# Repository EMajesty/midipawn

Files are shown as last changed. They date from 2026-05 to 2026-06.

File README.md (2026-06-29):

# midipawn

MIDI-controlled relay switcher built on the Raspberry Pi Pico (RP2040). Accepts MIDI over USB and TRS (GPIO 9). Controls 10 bypass relays via GPIO 10-19.

## MIDI interface

The device accepts messages on both USB MIDI and serial MIDI (TRS input on GPIO 9). Default MIDI channel is **6**.

### Relay control

Relay states are set via two CC messages. Each CC value is a 5-bit bitmask where bit 0 is the lowest-numbered relay in the group.

| CC  | Bit 0 | Bit 1 | Bit 2 | Bit 3 | Bit 4 |
|-----|---|---|---|---|---|
| 80  | Relay 1 (GPIO 10) | Relay 2 (GPIO 11) | Relay 3 (GPIO 12) | Relay 4 (GPIO 13) | Relay 5 (GPIO 14) |
| 81  | Relay 6 (GPIO 15) | Relay 7 (GPIO 16) | Relay 8 (GPIO 17) | Relay 9 (GPIO 18) | Relay 10 (GPIO 19) |

Example: sending CC 80 with value `0x15` (binary `10101`) activates relays 1, 3, 5 and deactivates relays 2, 4.

### Channel configuration

The MIDI channel is configurable via SysEx over USB and persists across power cycles (stored in flash).

```
F0 7D 01 <channel> F7
```

`<channel>` is `0x00`-`0x0F` for MIDI channels 1-16.

Example: `F0 7D 01 05 F7` sets the device to channel 6 (the default).

## Building

Requires [PlatformIO](https://platformio.org/).

```
cd firmware
pio run
```

## Flashing

Hold the BOOTSEL button on the Pico while plugging in USB, then:

```
cd firmware
pio run -t upload
```

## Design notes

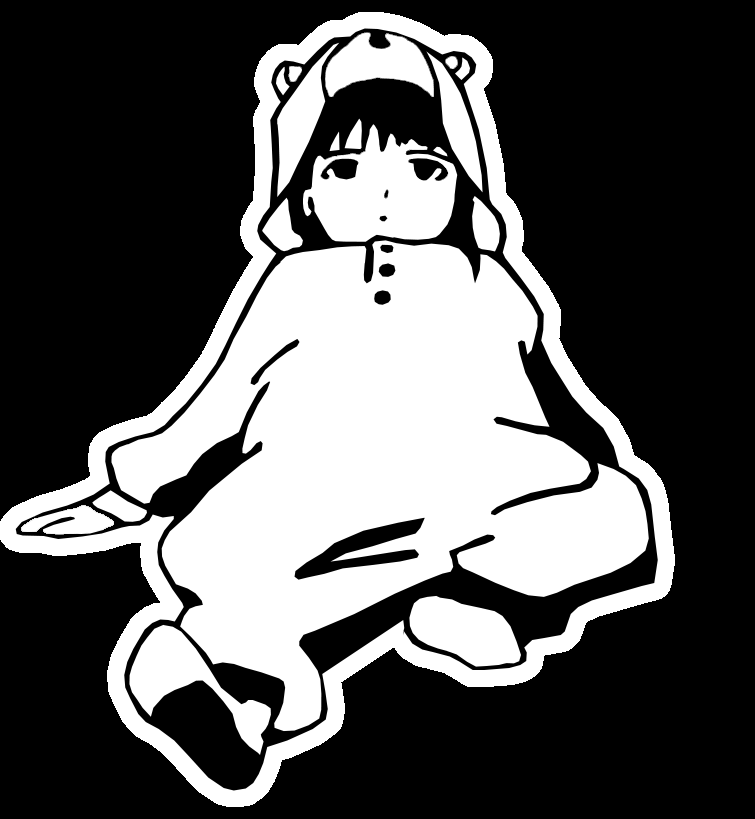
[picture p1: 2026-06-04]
hardware/lain.bmp

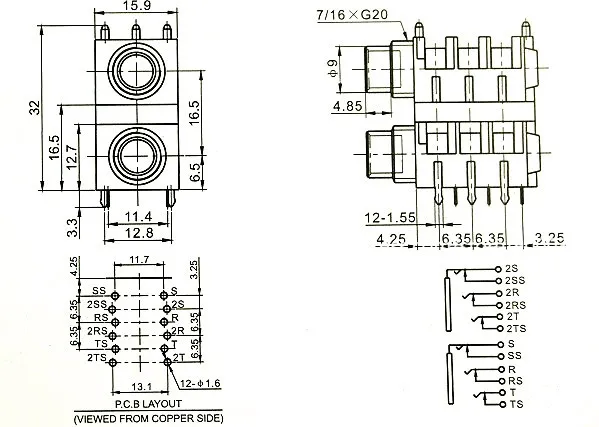
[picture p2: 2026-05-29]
docs/HTB1zdMtNVXXXXaDXXXXq6xXFXXX3.webp

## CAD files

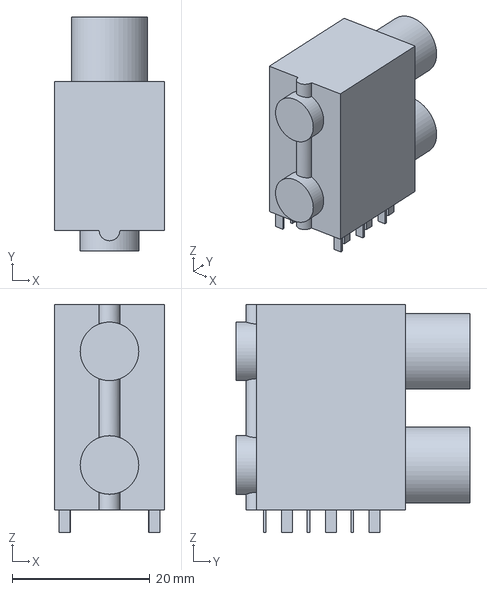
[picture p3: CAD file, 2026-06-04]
hardware/Jacks - Jacks.step
16.0 x 34.0 x 33.1 mm

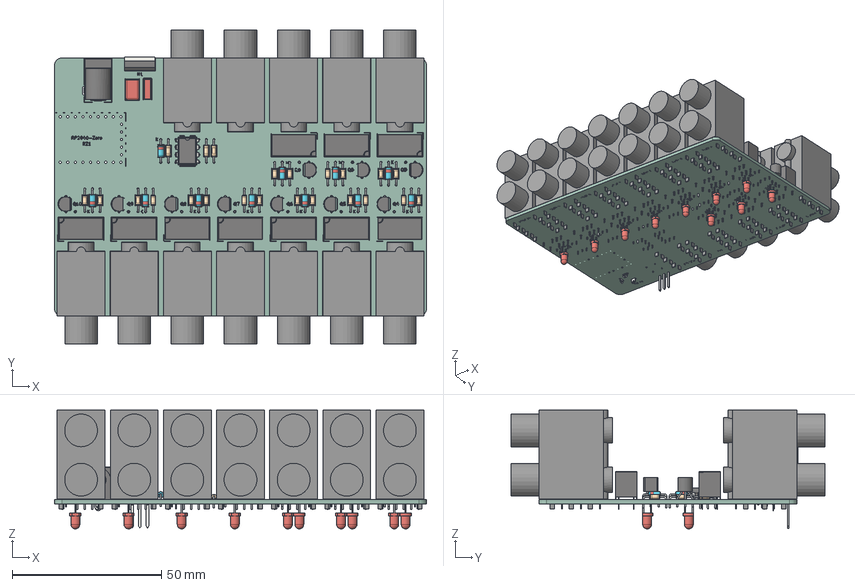
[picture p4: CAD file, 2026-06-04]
hardware/midipawn.step
124.5 x 105.2 x 39.8 mm
D_DO-35_SOD27_P7.62mm_Horizontal x 11
R_Axial_DIN0204_L3.6mm_D1.6mm_P7.62mm_Horizontal x 23
Relay_DPDT_Omron_G6S-2 x 10
Jacks - Jacks x 12
TO-92_Inline_Wide x 10
C_Rect_L7.0mm_W2.5mm_P5.00mm
C_Rect_L7.0mm_W4.5mm_P5.00mm
DIP-8_W7.62mm
TO-220-3_Vertical
BarrelJack_Horizontal
LED_D3.0mm x 10
midipawn_silkscreen x 2
midipawn_PCB

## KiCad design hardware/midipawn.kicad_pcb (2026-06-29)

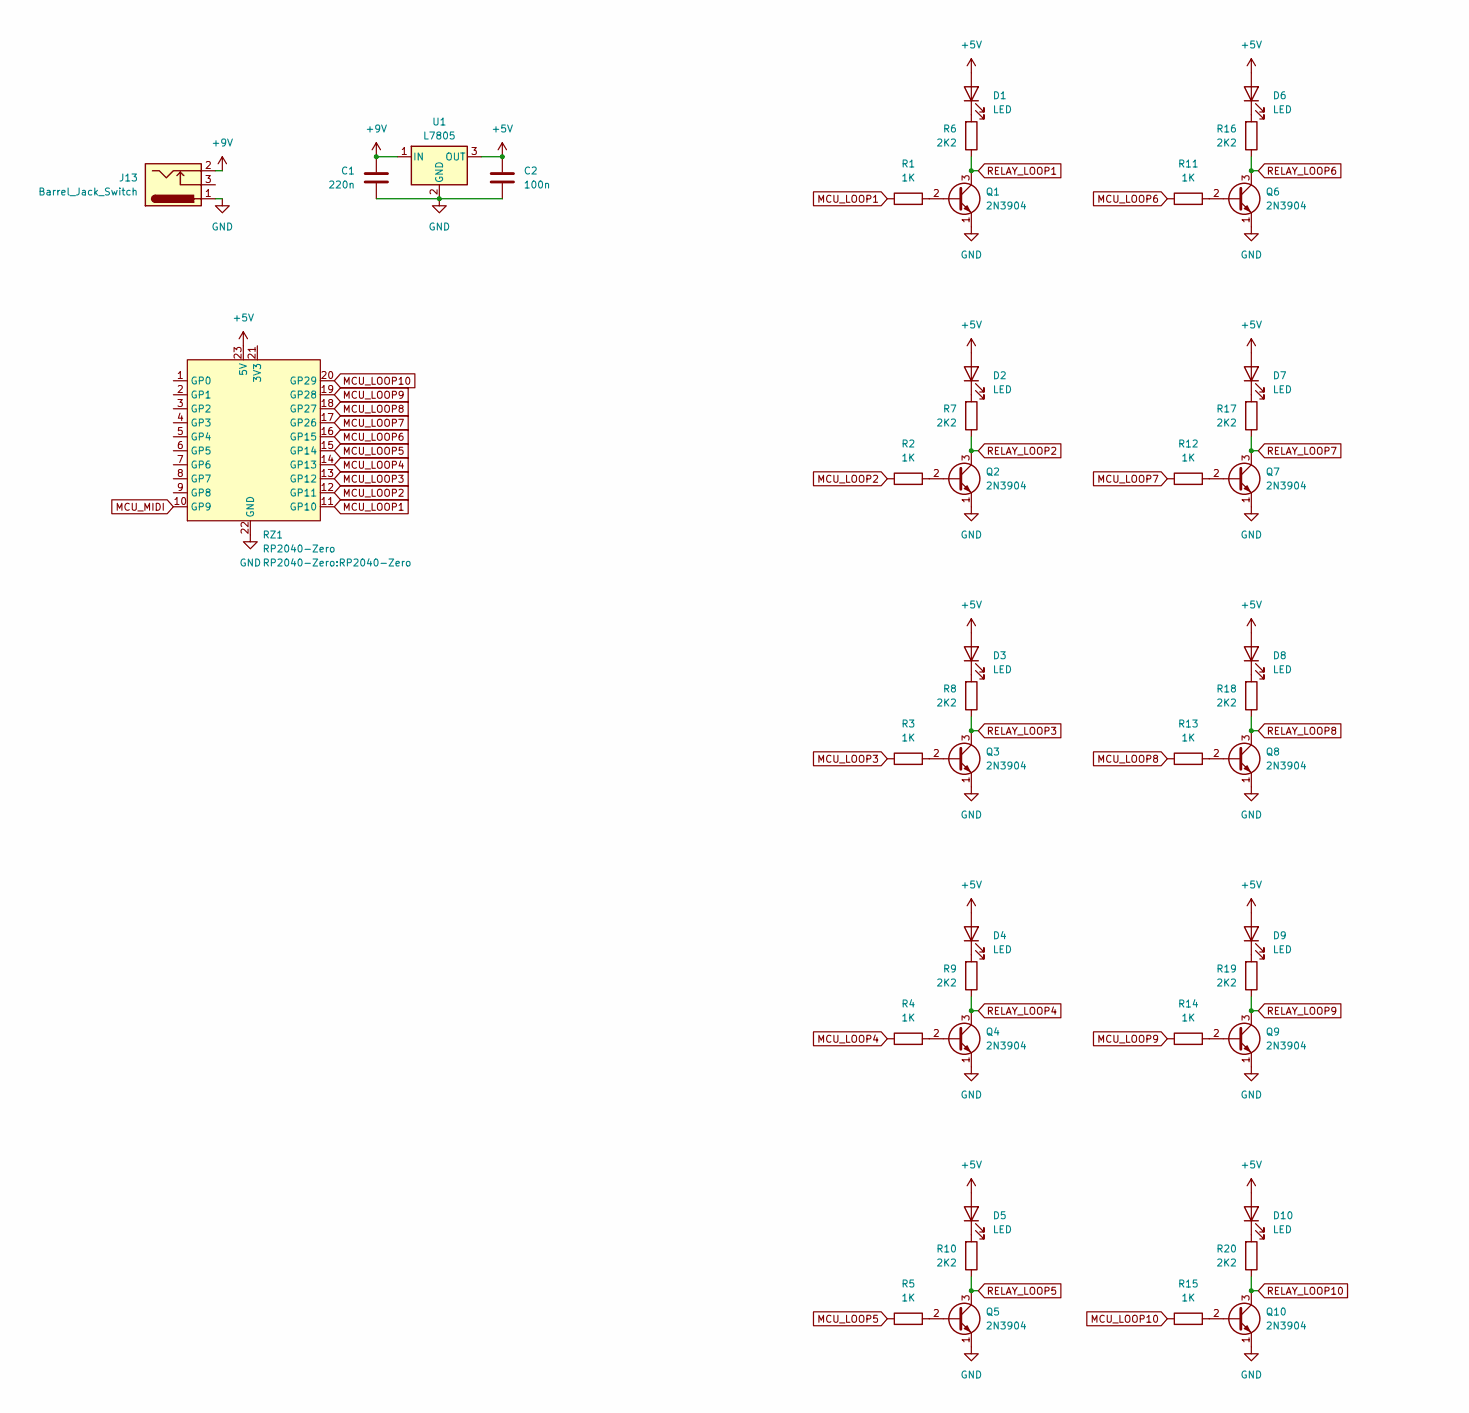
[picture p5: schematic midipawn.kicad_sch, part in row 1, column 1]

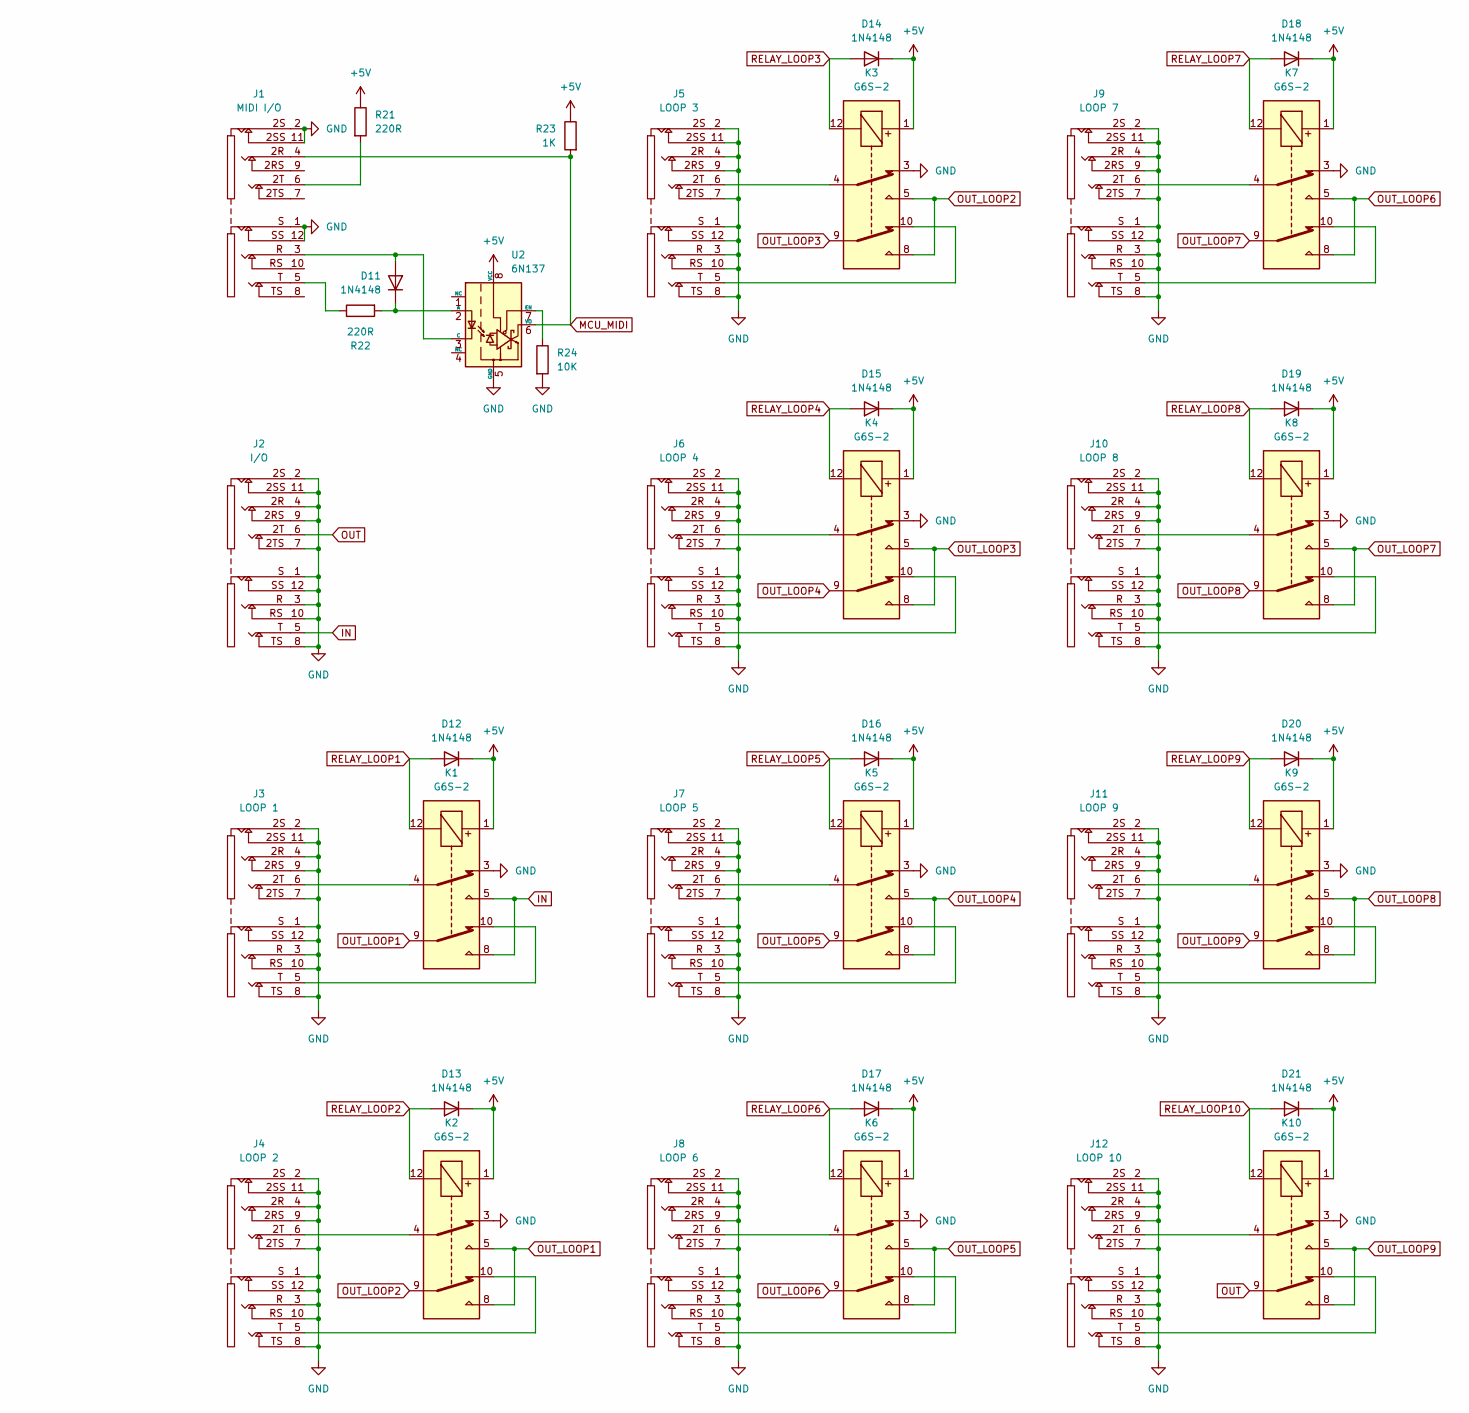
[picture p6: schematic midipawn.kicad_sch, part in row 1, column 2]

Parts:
C1: 220n; C_Rect_L7.0mm_W4.5mm_P5.00mm
C2: 100n; C_Rect_L7.0mm_W2.5mm_P5.00mm
D1, D2, D3, D4, D5, D6, D7, D8, D9, D10: LED; LED_D3.0mm
D11, D12, D13, D14, D15, D16, D17, D18, D19, D20, D21: 1N4148; D_DO-35_SOD27_P7.62mm_Horizontal
J1: MIDI I/O; CK635-037
J2: I/O; CK635-037
J3: LOOP 1; CK635-037
J4: LOOP 2; CK635-037
J5: LOOP 3; CK635-037
J6: LOOP 4; CK635-037
J7: LOOP 5; CK635-037
J8: LOOP 6; CK635-037
J9: LOOP 7; CK635-037
J10: LOOP 8; CK635-037
J11: LOOP 9; CK635-037
J12: LOOP 10; CK635-037
J13: Barrel_Jack_Switch; BarrelJack_Horizontal
K1, K2, K3, K4, K5, K6, K7, K8, K9, K10: G6S-2; Relay_DPDT_Omron_G6S-2
Q1, Q2, Q3, Q4, Q5, Q6, Q7, Q8, Q9, Q10: 2N3904; TO-92_Inline_Wide
R1, R2, R3, R4, R5, R11, R12, R13, R14, R15, R23: 1K; R_Axial_DIN0204_L3.6mm_D1.6mm_P7.62mm_Horizontal
R6, R7, R8, R9, R10, R16, R17, R18, R19, R20: 2K2; R_Axial_DIN0204_L3.6mm_D1.6mm_P7.62mm_Horizontal
R21, R22: 220R; R_Axial_DIN0204_L3.6mm_D1.6mm_P7.62mm_Horizontal
R24: 10K; R_Axial_DIN0204_L3.6mm_D1.6mm_P7.62mm_Horizontal
RZ1: RP2040-Zero
U1: L7805; TO-220-3_Vertical
U2: 6N137; DIP-8_W7.62mm

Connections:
+5V: C2.1, D1.2 (A), D2.2 (A), D3.2 (A), D4.2 (A), D5.2 (A), D6.2 (A), D7.2 (A), D8.2 (A), D9.2 (A), D10.2 (A), D12.1 (K), D13.1 (K), D14.1 (K), D15.1 (K), D16.1 (K), D17.1 (K), D18.1 (K), D19.1 (K), D20.1 (K), D21.1 (K), K1.1, K2.1, K3.1, K4.1, K5.1, K6.1, K7.1, K8.1, K9.1, K10.1, R21.1, R23.1, RZ1.23 (5V), U1.3 (OUT), U2.8 (VCC)
+9V: C1.1, J13.2, U1.1 (IN)
GND: C1.2, C2.2, J1.1 (S), J1.2 (2S), J1.11 (2SS), J1.12 (SS), J2.1 (S), J2.2 (2S), J2.3 (R), J2.4 (2R), J2.7 (2TS), J2.8 (TS), J2.9 (2RS), J2.10 (RS), J2.11 (2SS), J2.12 (SS), J3.1 (S), J3.2 (2S), J3.3 (R), J3.4 (2R), J3.7 (2TS), J3.8 (TS), J3.9 (2RS), J3.10 (RS), J3.11 (2SS), J3.12 (SS), J4.1 (S), J4.2 (2S), J4.3 (R), J4.4 (2R), J4.7 (2TS), J4.8 (TS), J4.9 (2RS), J4.10 (RS), J4.11 (2SS), J4.12 (SS), J5.1 (S), J5.2 (2S), J5.3 (R), J5.4 (2R), J5.7 (2TS), J5.8 (TS), J5.9 (2RS), J5.10 (RS), J5.11 (2SS), J5.12 (SS), J6.1 (S), J6.2 (2S), J6.3 (R), J6.4 (2R), J6.7 (2TS), J6.8 (TS), J6.9 (2RS), J6.10 (RS), J6.11 (2SS), J6.12 (SS), J7.1 (S), J7.2 (2S), J7.3 (R), J7.4 (2R), J7.7 (2TS), J7.8 (TS), J7.9 (2RS), J7.10 (RS), J7.11 (2SS), J7.12 (SS), J8.1 (S), J8.2 (2S), J8.3 (R), J8.4 (2R), J8.7 (2TS), J8.8 (TS), J8.9 (2RS), J8.10 (RS), J8.11 (2SS), J8.12 (SS), J9.1 (S), J9.2 (2S), J9.3 (R), J9.4 (2R), J9.7 (2TS), J9.8 (TS), J9.9 (2RS), J9.10 (RS), J9.11 (2SS), J9.12 (SS), J10.1 (S), J10.2 (2S), J10.3 (R), J10.4 (2R), J10.7 (2TS), J10.8 (TS), J10.9 (2RS), J10.10 (RS), J10.11 (2SS), J10.12 (SS), J11.1 (S), J11.2 (2S), J11.3 (R), J11.4 (2R), J11.7 (2TS), J11.8 (TS), J11.9 (2RS), J11.10 (RS), J11.11 (2SS), J11.12 (SS), J12.1 (S), J12.2 (2S), J12.3 (R), J12.4 (2R), J12.7 (2TS), J12.8 (TS), J12.9 (2RS), J12.10 (RS), J12.11 (2SS), J12.12 (SS), J13.1, K1.3, K2.3, K3.3, K4.3, K5.3, K6.3, K7.3, K8.3, K9.3, K10.3, Q1.1 (E), Q2.1 (E), Q3.1 (E), Q4.1 (E), Q5.1 (E), Q6.1 (E), Q7.1 (E), Q8.1 (E), Q9.1 (E), Q10.1 (E), R24.2, RZ1.22 (GND), U1.2 (GND), U2.5 (GND)
IN: J2.5 (T), K1.5, K1.8
MCU_LOOP1: R1.1, RZ1.11 (GP10)
MCU_LOOP2: R2.1, RZ1.12 (GP11)
MCU_LOOP3: R3.1, RZ1.13 (GP12)
MCU_LOOP4: R4.1, RZ1.14 (GP13)
MCU_LOOP5: R5.1, RZ1.15 (GP14)
MCU_LOOP6: R11.1, RZ1.16 (GP15)
MCU_LOOP7: R12.1, RZ1.17 (GP26)
MCU_LOOP8: R13.1, RZ1.18 (GP27)
MCU_LOOP9: R14.1, RZ1.19 (GP28)
MCU_LOOP10: R15.1, RZ1.20 (GP29)
MCU_MIDI: J1.4 (2R), R23.2, RZ1.10 (GP9), U2.6 (VO)
unnamed: D1.1 (K), R6.2
unnamed: D2.1 (K), R7.2
unnamed: D3.1 (K), R8.2
unnamed: D4.1 (K), R9.2
unnamed: D5.1 (K), R10.2
unnamed: D6.1 (K), R16.2
unnamed: D7.1 (K), R17.2
unnamed: D8.1 (K), R18.2
unnamed: D9.1 (K), R19.2
unnamed: D10.1 (K), R20.2
unnamed: D11.2 (A), J1.3 (R), U2.3 (C)
unnamed: D11.1 (K), R22.2, U2.2 (A)
unnamed: J1.6 (2T), R21.2
unnamed: J1.5 (T), R22.1
unnamed: J3.6 (2T), K1.4
unnamed: J3.5 (T), K1.10
unnamed: J4.6 (2T), K2.4
unnamed: J4.5 (T), K2.10
unnamed: J5.6 (2T), K3.4
unnamed: J5.5 (T), K3.10
unnamed: J6.6 (2T), K4.4
unnamed: J6.5 (T), K4.10
unnamed: J7.6 (2T), K5.4
unnamed: J7.5 (T), K5.10
unnamed: J8.6 (2T), K6.4
unnamed: J8.5 (T), K6.10
unnamed: J9.6 (2T), K7.4
unnamed: J9.5 (T), K7.10
unnamed: J10.6 (2T), K8.4
unnamed: J10.5 (T), K8.10
unnamed: J11.6 (2T), K9.4
unnamed: J11.5 (T), K9.10
unnamed: J12.6 (2T), K10.4
unnamed: J12.5 (T), K10.10
unnamed: Q1.2 (B), R1.2
unnamed: Q2.2 (B), R2.2
unnamed: Q3.2 (B), R3.2
unnamed: Q4.2 (B), R4.2
unnamed: Q5.2 (B), R5.2
unnamed: Q6.2 (B), R11.2
unnamed: Q7.2 (B), R12.2
unnamed: Q8.2 (B), R13.2
unnamed: Q9.2 (B), R14.2
unnamed: Q10.2 (B), R15.2
unnamed: R24.1, U2.7 (EN)
OUT: J2.6 (2T), K10.9
OUT_LOOP1: K1.9, K2.5, K2.8
OUT_LOOP2: K2.9, K3.5, K3.8
OUT_LOOP3: K3.9, K4.5, K4.8
OUT_LOOP4: K4.9, K5.5, K5.8
OUT_LOOP5: K5.9, K6.5, K6.8
OUT_LOOP6: K6.9, K7.5, K7.8
OUT_LOOP7: K7.9, K8.5, K8.8
OUT_LOOP8: K8.9, K9.5, K9.8
OUT_LOOP9: K9.9, K10.5, K10.8
RELAY_LOOP1: D12.2 (A), K1.12, Q1.3 (C), R6.1
RELAY_LOOP2: D13.2 (A), K2.12, Q2.3 (C), R7.1
RELAY_LOOP3: D14.2 (A), K3.12, Q3.3 (C), R8.1
RELAY_LOOP4: D15.2 (A), K4.12, Q4.3 (C), R9.1
RELAY_LOOP5: D16.2 (A), K5.12, Q5.3 (C), R10.1
RELAY_LOOP6: D17.2 (A), K6.12, Q6.3 (C), R16.1
RELAY_LOOP7: D18.2 (A), K7.12, Q7.3 (C), R17.1
RELAY_LOOP8: D19.2 (A), K8.12, Q8.3 (C), R18.1
RELAY_LOOP9: D20.2 (A), K9.12, Q9.3 (C), R19.1
RELAY_LOOP10: D21.2 (A), K10.12, Q10.3 (C), R20.1

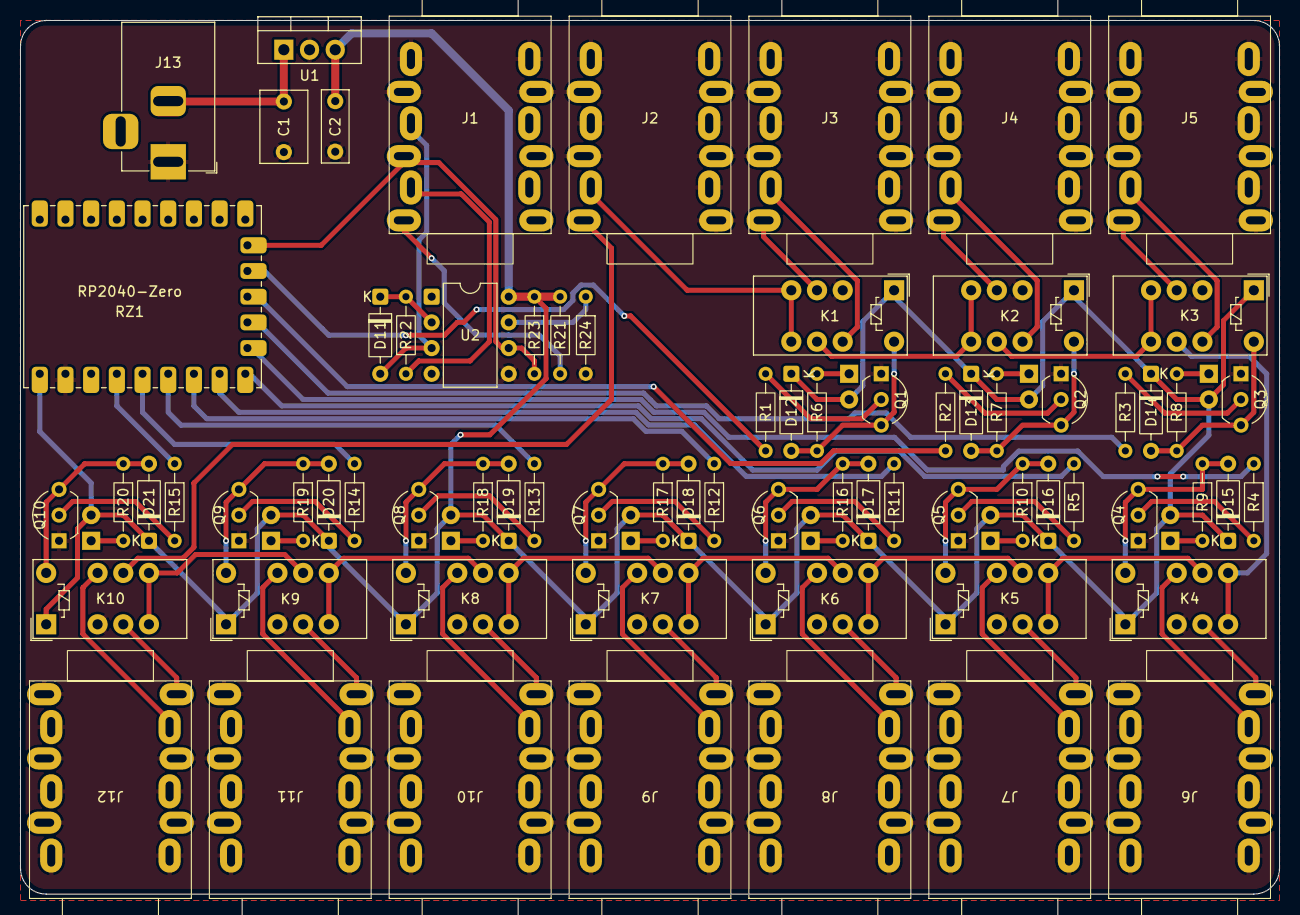
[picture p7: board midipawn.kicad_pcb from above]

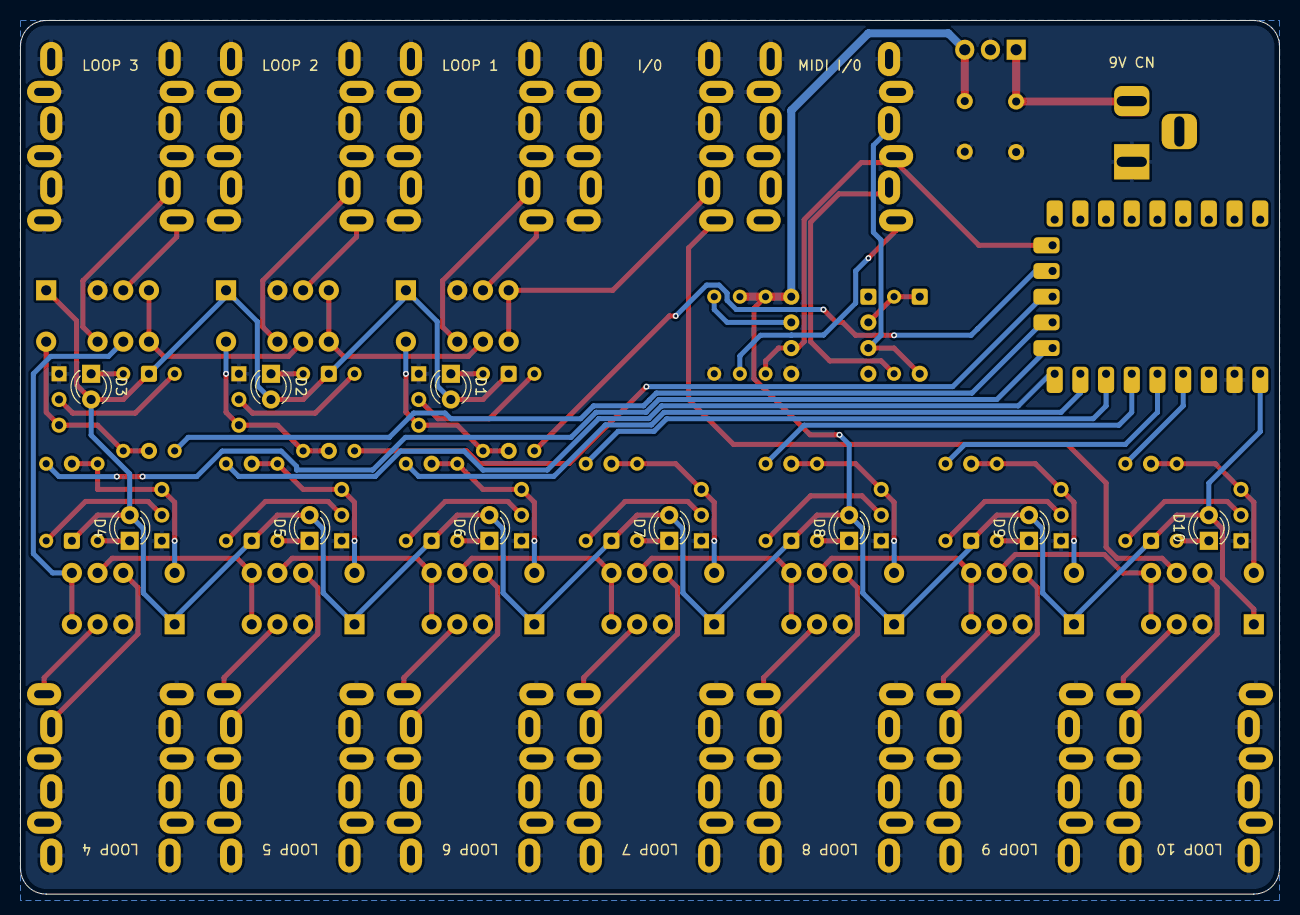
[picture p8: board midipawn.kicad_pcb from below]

Board: 2 copper layers, 124.5 x 86.4 mm, 83 parts (10 on the bottom side), 80 nets.

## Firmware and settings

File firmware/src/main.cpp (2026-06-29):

#include <Adafruit_TinyUSB.h>
#include <Arduino.h>
#include <EEPROM.h>
#include <MIDI.h>

#define EEPROM_SIZE 2
#define EEPROM_MAGIC 0xA5
#define ADDR_MAGIC 0
#define ADDR_CHANNEL 1
#define DEFAULT_CHANNEL 6

// SysEx: F0 7D 01 <0x00-0x0F> F7 — set MIDI channel 1-16
#define SYSEX_MFR_ID 0x7D // Non-commercial / educational
#define SYSEX_CMD_SET_CHANNEL 0x01

// CC 80 bits 0-4: relays 1-5 (GPIO 10-14)
// CC 81 bits 0-4: relays 6-10 (GPIO 15-19)
#define CC_RELAY_A 80
#define CC_RELAY_B 81
#define RELAY_BASE 10

Adafruit_USBD_MIDI usb_midi;

MIDI_CREATE_INSTANCE(Adafruit_USBD_MIDI, usb_midi, USBMIDI);
MIDI_CREATE_INSTANCE(HardwareSerial, Serial2, SerialMIDI);

midi::Channel loadChannel() {
    EEPROM.begin(EEPROM_SIZE);
    if (EEPROM.read(ADDR_MAGIC) == EEPROM_MAGIC) {
        uint8_t ch = EEPROM.read(ADDR_CHANNEL);
        if (ch >= 1 && ch <= 16)
            return (midi::Channel)ch;
    }
    return (midi::Channel)DEFAULT_CHANNEL;
}

void saveChannel(midi::Channel ch) {
    EEPROM.write(ADDR_MAGIC, EEPROM_MAGIC);
    EEPROM.write(ADDR_CHANNEL, (uint8_t)ch);
    EEPROM.commit();
}

void setChannel(midi::Channel ch) {
    SerialMIDI.setInputChannel(ch);
    USBMIDI.setInputChannel(ch);
    saveChannel(ch);
}

void handleCC(byte channel, byte number, byte value) {
    if (number == CC_RELAY_A || number == CC_RELAY_B) {
        int offset = (number == CC_RELAY_A) ? 0 : 5;
        for (int i = 0; i < 5; i++)
            digitalWrite(RELAY_BASE + offset + i, (value >> i) & 1);
    }
}

void handleSysEx(byte *data, unsigned size) {
    // MIDI library passes data starting with F0, without trailing F7
    if (size >= 4 && data[0] == 0xF0 && data[1] == SYSEX_MFR_ID &&
        data[2] == SYSEX_CMD_SET_CHANNEL) {
        uint8_t ch = data[3] + 1; // 0x00-0x0F -> 1-16
        if (ch >= 1 && ch <= 16)
            setChannel((midi::Channel)ch);
    }
}

void setup() {
    for (int pin = 10; pin <= 29; pin++) {
        pinMode(pin, OUTPUT);
    }

    midi::Channel ch = loadChannel();

    Serial2.setRX(9);
    SerialMIDI.begin(ch);
    SerialMIDI.turnThruOff();

    USBMIDI.begin(ch);
    USBMIDI.turnThruOff();
    SerialMIDI.setHandleControlChange(handleCC);
    USBMIDI.setHandleControlChange(handleCC);
    USBMIDI.setHandleSystemExclusive(handleSysEx);
}

void loop() {
    SerialMIDI.read();
    USBMIDI.read();
}

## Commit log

2026-05-29 Prompt is too long
    [midipawn.kicad_pcb, midipawn.kicad_sch]
2026-06-04 Add STEP 3D model for audio jacks connector
    [Jacks - Jacks.step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]
2026-06-04 Adjust audio jack positions to align with board edge
    [midipawn.kicad_pcb]
2026-06-16 Update PCB layout and regenerate Gerber fabrication files
    [midipawn-B_Cu.gbr, midipawn-B_Mask.gbr, midipawn-B_Paste.gbr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]
2026-06-29 Add pull-down resistor on voltage regulator enable pin
    [midipawn.kicad_pcb, midipawn.kicad_sch]
2026-06-29 Add .gitignore for KiCad, PlatformIO, Nix, and OS artifacts
2026-06-29 Replace DIN with TRS for MIDI input connector references
